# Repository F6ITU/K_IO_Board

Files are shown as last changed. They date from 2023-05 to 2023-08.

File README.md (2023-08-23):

# K_IO_Board
LA2NI's OpenHPSDR I/O Board (Kicad Version)

OpenHPSDR P.A. OpenHPSDR Input/Output board by LA2NI (Munin 400)

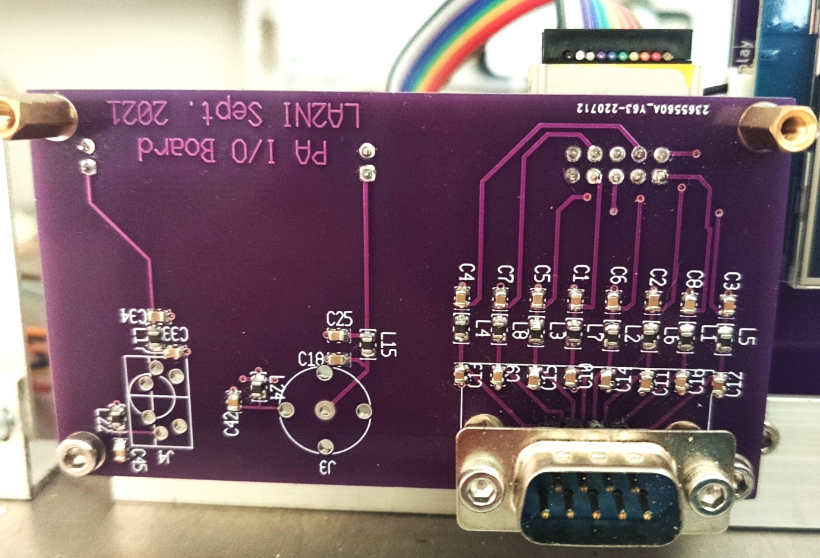
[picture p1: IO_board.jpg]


This picture shows an early design of the I/O board by LA2NI

This I/O board is part of a set consisting of a 400 W LDMos based RF power amplifier (Munin 400), 
a medium power (600 or 1500 W) Zolotarev low pass filter, an Automatic Antenna Tuner (ATU) nickname « Aries » 
and a 4 port antenna switch.

All these developments are the work and intellectual property of Kjell Karlsen LA2NI and Laurence Barker G8NJJ.

This original work can be downloaded from 

https://github.com/LA2NI/

https://github.com/laurencebarker

The I/O board ensures the physical link between the transceiver and the "Munin400/Aries" RF system

For more information, please refer to the Aries documentation (in the G8NJJ github repository)

This board was originally developed in September 2021 by Kjell LA2NI , with UltiBoard EDA. A very early release has been designed
using KiCAD EDA. After some test on a prototype setup, it has been decided to extend this board to offer both P1/output jack and
the full set of J1 signal output and a 12V switched power supply rail for the OpenHPSDR Andromeda interface. All internal or external
"tune" trace that can be found on the original f5 release of the I/O board schematic have been deleted

This design is protected by the CERN Open source/ Open hardware Licence.

Kicad is an Opensource EDA software maintained by the European Reseach Center CERN (Conseil européen pour la recherche nucléaire)

The original work is protected by the TAPR Open Hardware licence
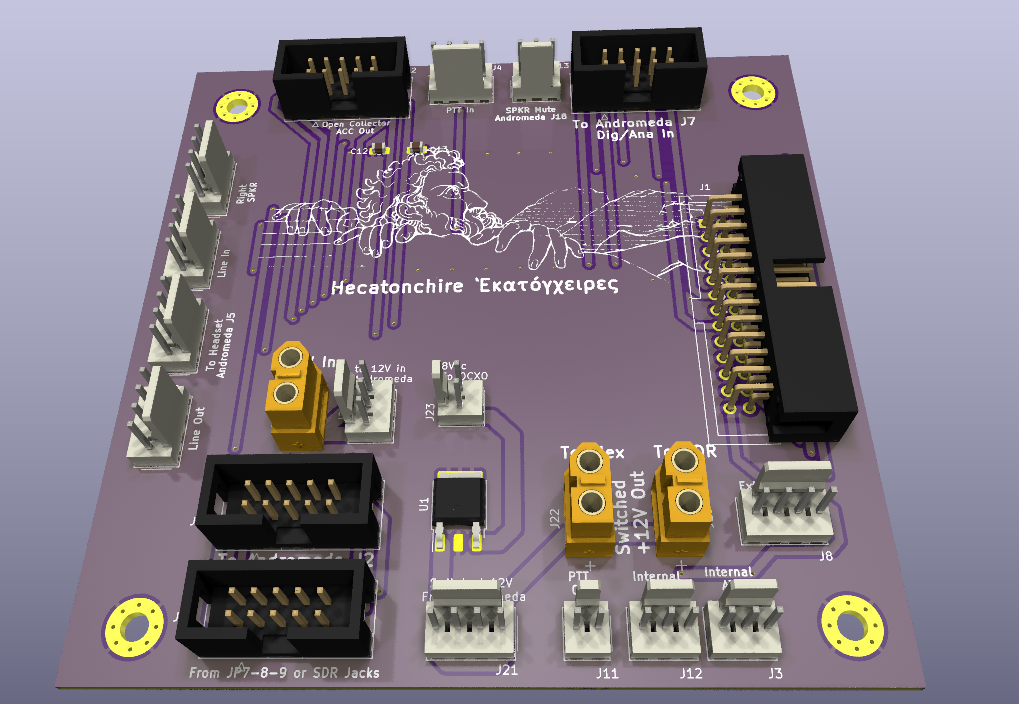
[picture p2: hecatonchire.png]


Gerber files could be downloaded at https://github.com/F6ITU/K_IO_Board/tree/main/Gerber 

An interactive BOM is also available https://github.com/F6ITU/K_IO_Board/tree/main/iBom

This version is -so far- considered as a "final and usable" version. As usual, all improvement suggestions are welcome.

73' , Enjoy

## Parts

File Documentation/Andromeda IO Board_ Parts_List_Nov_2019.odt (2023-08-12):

Andromeda I/O Board Parts List.

Nov. 2019

47 pcs. 10nF Size 0603

C1- C45, C47. Do not install C21, C22, C29, C30, C41

on LINE Out.

1 pcs. 2x13 26 pin Header Molex PN: 70247-2651

J1 Mouser PN: 538-70247-2651

1 pcs. 9 pin Delta Header, Female Harting PN: 09641127235 (https://www.digikey.com/product-detail/en/harting/09641127235/1195-2367-ND/3180950)

J2 DigiKey PN: 1195-2367-ND (https://www.digikey.com/product-detail/en/harting/09641127235/1195-2367-ND/3180950)

Mouser PN: 617-09-64-112-7235

1 pcs. RCA header. Pro-Signal PN: MJ-573P

J11 Farnell PN: 1267399

5 pcs. 3,5mm Stereo Jack Molex PN: 0472570001

J4-J8 Mouser PN: 538-47257-0001

DigiKey PN: WM17366-ND

1 pcs. Header1x3 Molex PN: 38-00-6293

Mouser PN: 538-38-00-6293

1 pcs. Header 1x4 Molex PN: 22-23-2042

Mouser PN: 538-22-23-2042

1 pcs. Header 2x5 10 pin header Molex PN 70246-1003

Mouser PN:538-70246-1003

26pcs. Ferrite Beads Wurth Elektronik PN: 742792514

L1-L20, L22-L27 Mouser PN: 710-742792514

DigiKey PN: 732-1643-2-ND

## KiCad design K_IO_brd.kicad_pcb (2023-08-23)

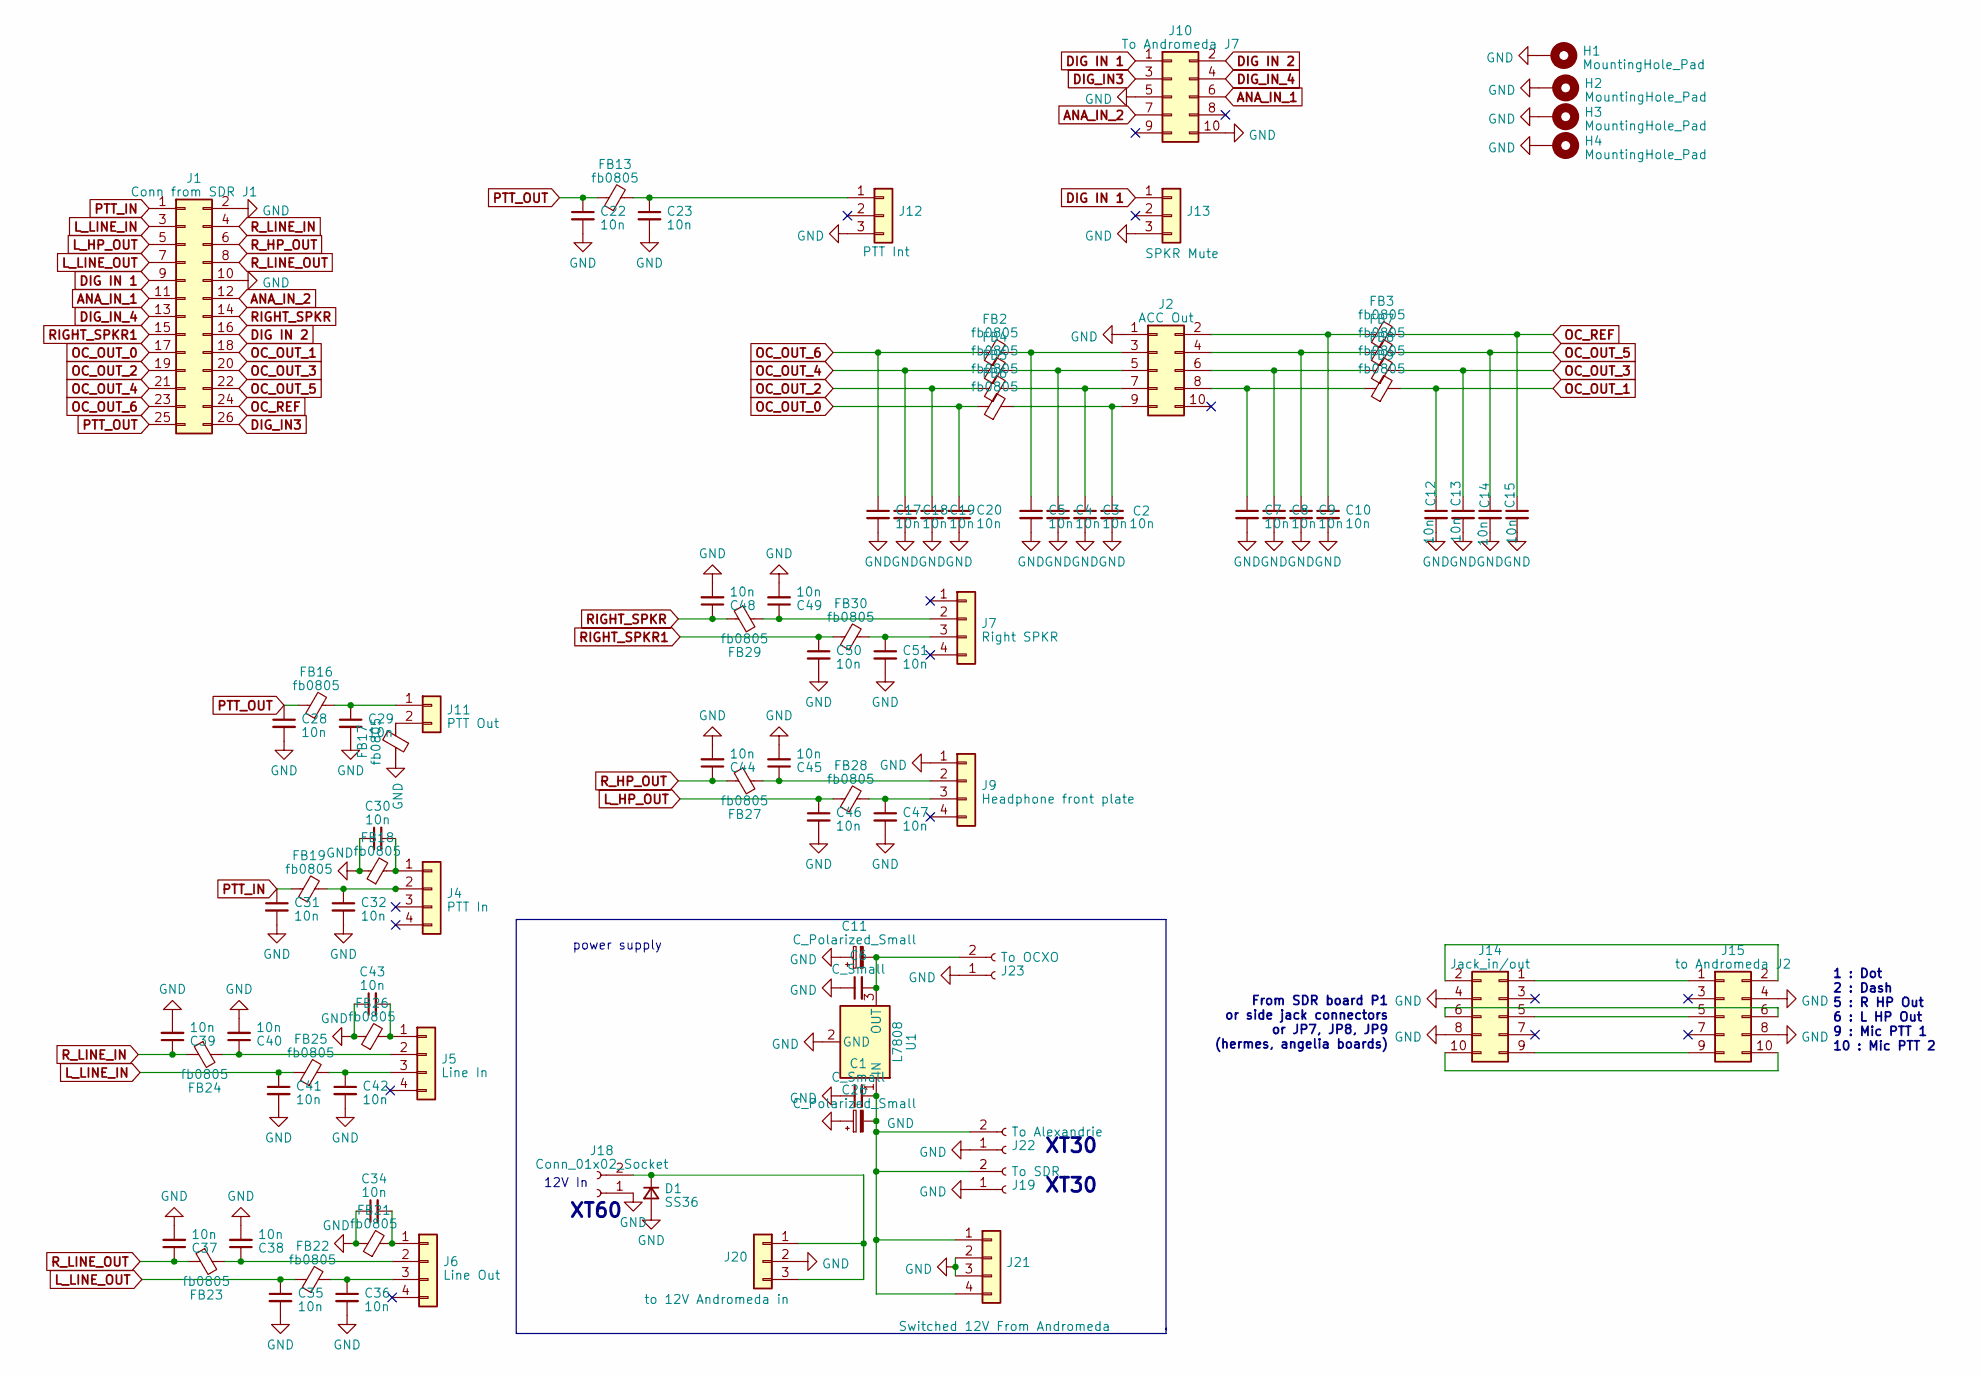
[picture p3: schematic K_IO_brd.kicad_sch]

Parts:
C1, C6: C_Small; C_0805_2012Metric_Pad1.18x1.45mm_HandSolder
C2, C3, C4, C5, C7, C8, C9, C10, C12, C13, C14, C15, C17, C18, C19, C20, C22, C23, C28, C29, C30, C31, C32, C34, C35, C36, C37, C38, C39, C40, C41, C42, C43, C44, C45, C46, C47, C48, C49, C50, C51: 10n; C_0805_2012Metric_Pad1.18x1.45mm_HandSolder
C11, C26: C_Polarized_Small; C_2220_5650Metric_Pad1.97x5.40mm_HandSolder
D1: SS36; D_SMC
FB2, FB3, FB4, FB5, FB6, FB7, FB8, FB9, FB13, FB16, FB17, FB18, FB19, FB21, FB22, FB23, FB24, FB25, FB26, FB27, FB28, FB29, FB30: fb0805; L_0805_2012Metric_Pad1.15x1.40mm_HandSolder
H1, H2, H3, H4: MountingHole_Pad; MountingHole_3.5mm_Pad_Via
J1: Conn from SDR J1; IDC-Header_2x13_P2.54mm_Vertical
J2: ACC Out; IDC-Header_2x05_P2.54mm_Vertical
J4: PTT In; Molex_KK-254_AE-6410-04A_1x04_P2.54mm_Vertical
J5: Line In; Molex_KK-254_AE-6410-04A_1x04_P2.54mm_Vertical
J6: Line Out; Molex_KK-254_AE-6410-04A_1x04_P2.54mm_Vertical
J7: Right SPKR; Molex_KK-254_AE-6410-04A_1x04_P2.54mm_Vertical
J9: Headphone front plate; Molex_KK-254_AE-6410-04A_1x04_P2.54mm_Vertical
J10: To Andromeda J7; IDC-Header_2x05_P2.54mm_Vertical
J11: PTT Out; Molex_KK-254_AE-6410-02A_1x02_P2.54mm_Vertical
J12: PTT Int; Molex_KK-254_AE-6410-03A_1x03_P2.54mm_Vertical
J13: SPKR Mute; Molex_KK-254_AE-6410-03A_1x03_P2.54mm_Vertical
J14: Jack_in/out; IDC-Header_2x05_P2.54mm_Vertical
J15: to Andromeda J2; IDC-Header_2x05_P2.54mm_Vertical
J18: Conn_01x02_Socket; AMASS_XT30U-F_1x02_P5.0mm_Vertical
J19: To SDR; AMASS_XT30U-F_1x02_P5.0mm_Vertical
J20: to 12V Andromeda in; Molex_KK-254_AE-6410-03A_1x03_P2.54mm_Vertical
J21: Switched 12V From Andromeda; Molex_KK-254_AE-6410-04A_1x04_P2.54mm_Vertical
J22: To Alexandrie; AMASS_XT30U-F_1x02_P5.0mm_Vertical
J23: To OCXO; Molex_KK-254_AE-6410-02A_1x02_P2.54mm_Vertical
U1: L7808; TO-252-3_TabPin2

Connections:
ANA_IN_1: J1.11, J10.6
ANA_IN_2: J1.12, J10.7
DIG IN 1: J1.9, J10.1, J13.1
DIG IN 2: J1.16, J10.2
DIG_IN3: J1.26, J10.3
DIG_IN_4: J1.13, J10.4
GND: C1.1, C2.2, C3.2, C4.2, C5.2, C6.1, C7.2, C8.2, C9.2, C10.2, C11.1, C12.2, C13.2, C14.2, C15.2, C17.2, C18.2, C19.2, C20.2, C22.2, C23.2, C26.1, C28.2, C29.2, C30.1, C31.2, C32.2, C34.1, C35.2, C36.2, C37.2, C38.2, C39.2, C40.2, C41.2, C42.2, C43.1, C44.2, C45.2, C46.2, C47.2, C48.2, C49.2, C50.2, C51.2, D1.2 (A), FB17.1, FB18.1, FB21.1, FB26.1, H1.1, H2.1, H3.1, H4.1, J1.2, J1.10, J2.1, J9.1, J10.5, J10.10, J12.3, J13.3, J14.4, J14.8, J15.4, J15.8, J18.1, J19.1, J20.2, J21.2, J21.3, J22.1, J23.1, U1.2 (GND)
L_HP_OUT: C46.1, FB28.1, J1.5
L_LINE_IN: C41.1, FB25.1, J1.3
L_LINE_OUT: C35.1, FB22.1, J1.7
unnamed: D1.1 (K), J18.2, J20.1, J20.3
unnamed: C10.1, FB3.1, J2.2
unnamed: C5.1, FB2.2, J2.3
unnamed: C9.1, FB7.1, J2.4
unnamed: C4.1, FB4.2, J2.5
unnamed: C8.1, FB8.1, J2.6
unnamed: C3.1, FB5.2, J2.7
unnamed: C7.1, FB9.1, J2.8
unnamed: C2.1, FB6.2, J2.9
unnamed: C30.2, FB18.2, J4.1
unnamed: C32.1, FB19.2, J4.2
unnamed: C43.2, FB26.2, J5.1
unnamed: C40.1, FB24.2, J5.2
unnamed: C42.1, FB25.2, J5.3
unnamed: C34.2, FB21.2, J6.1
unnamed: C38.1, FB23.2, J6.2
unnamed: C36.1, FB22.2, J6.3
unnamed: C49.1, FB29.2, J7.2
unnamed: C51.1, FB30.2, J7.3
unnamed: C45.1, FB27.2, J9.2
unnamed: C47.1, FB28.2, J9.3
unnamed: C29.1, FB16.2, J11.1
unnamed: FB17.2, J11.2
unnamed: C23.1, FB13.2, J12.1
unnamed: J14.1, J15.1
unnamed: J14.2, J15.2
unnamed: J14.5, J15.5
unnamed: J14.6, J15.6
unnamed: J14.9, J15.9
unnamed: J14.10, J15.10
unnamed: C1.2, C26.2, J19.2, J21.1, J21.4, J22.2, U1.1 (IN)
unnamed: C6.2, C11.2, J23.2, U1.3 (OUT)
OC_OUT_0: C20.1, FB6.1, J1.17
OC_OUT_1: C12.1, FB9.2, J1.18
OC_OUT_2: C19.1, FB5.1, J1.19
OC_OUT_3: C13.1, FB8.2, J1.20
OC_OUT_4: C18.1, FB4.1, J1.21
OC_OUT_5: C14.1, FB7.2, J1.22
OC_OUT_6: C17.1, FB2.1, J1.23
OC_REF: C15.1, FB3.2, J1.24
PTT_IN: C31.1, FB19.1, J1.1
PTT_OUT: C22.1, C28.1, FB13.1, FB16.1, J1.25
RIGHT_SPKR: C48.1, FB29.1, J1.14
RIGHT_SPKR1: C50.1, FB30.1, J1.15
R_HP_OUT: C44.1, FB27.1, J1.6
R_LINE_IN: C39.1, FB24.1, J1.4
R_LINE_OUT: C37.1, FB23.1, J1.8

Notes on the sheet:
XT60
power supply
XT30
12V In
1 : Dot 2 : Dash 5 : R HP Out 6 : L HP Out 9 : Mic PTT 1 10 : Mic PTT 2
From SDR board P1 or side jack connectors or JP7, JP8, JP9 (hermes, angelia boards)

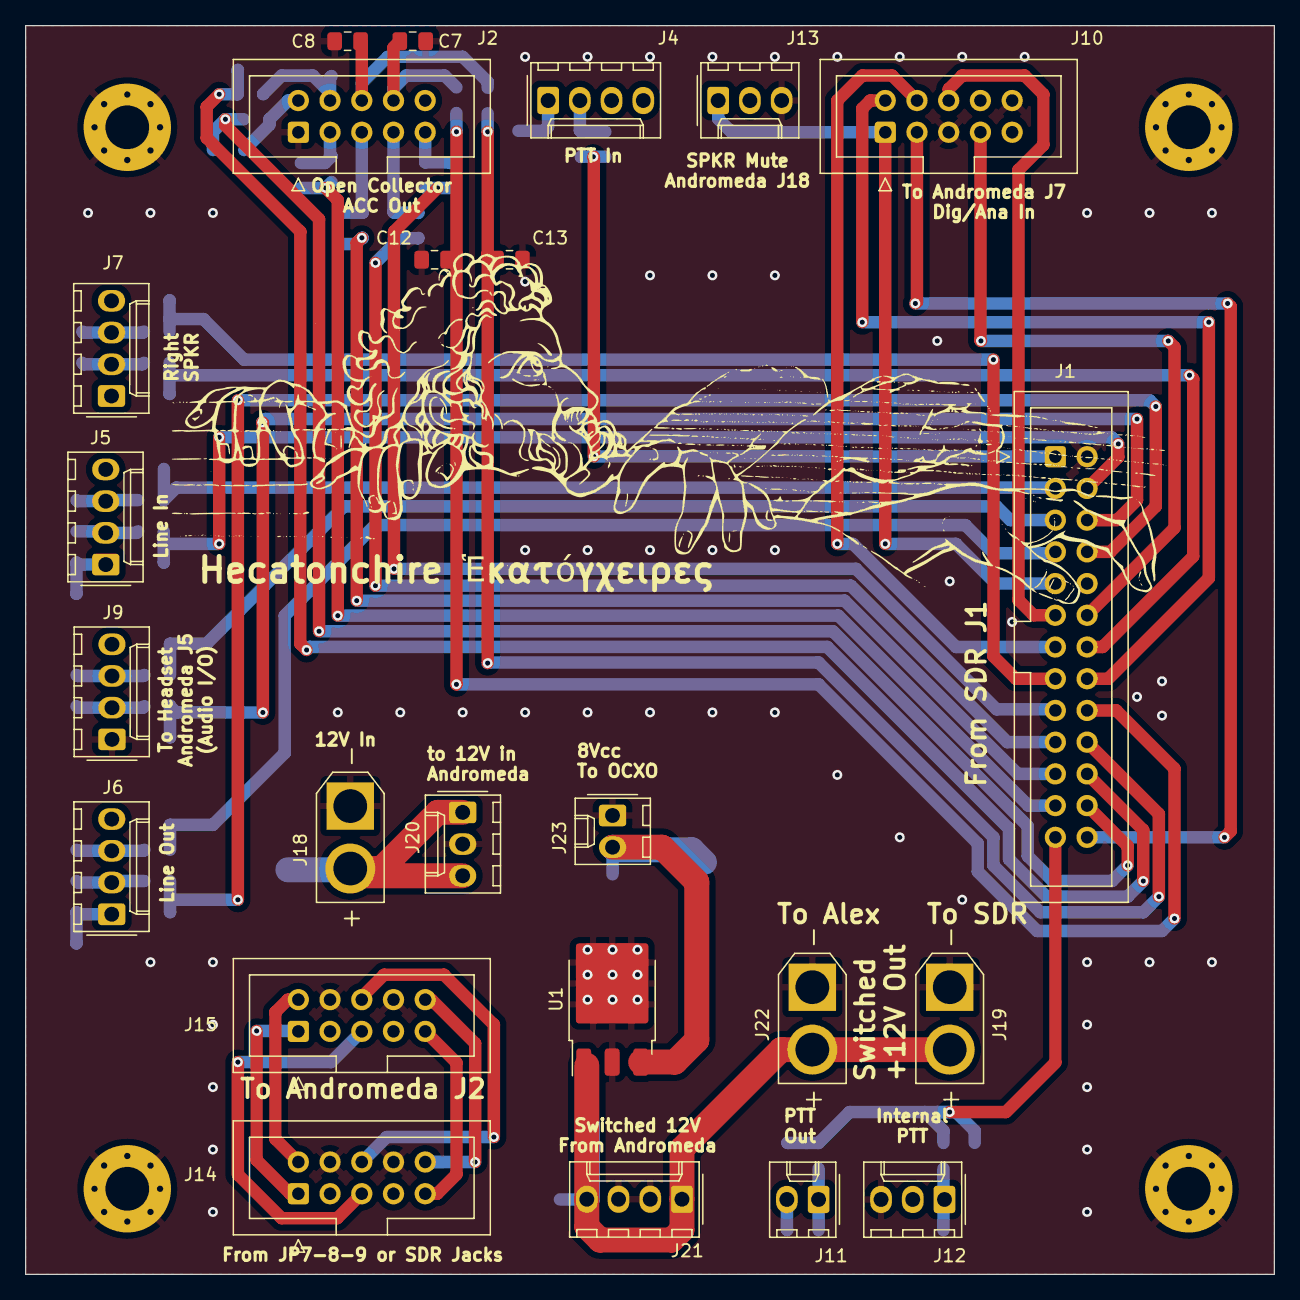
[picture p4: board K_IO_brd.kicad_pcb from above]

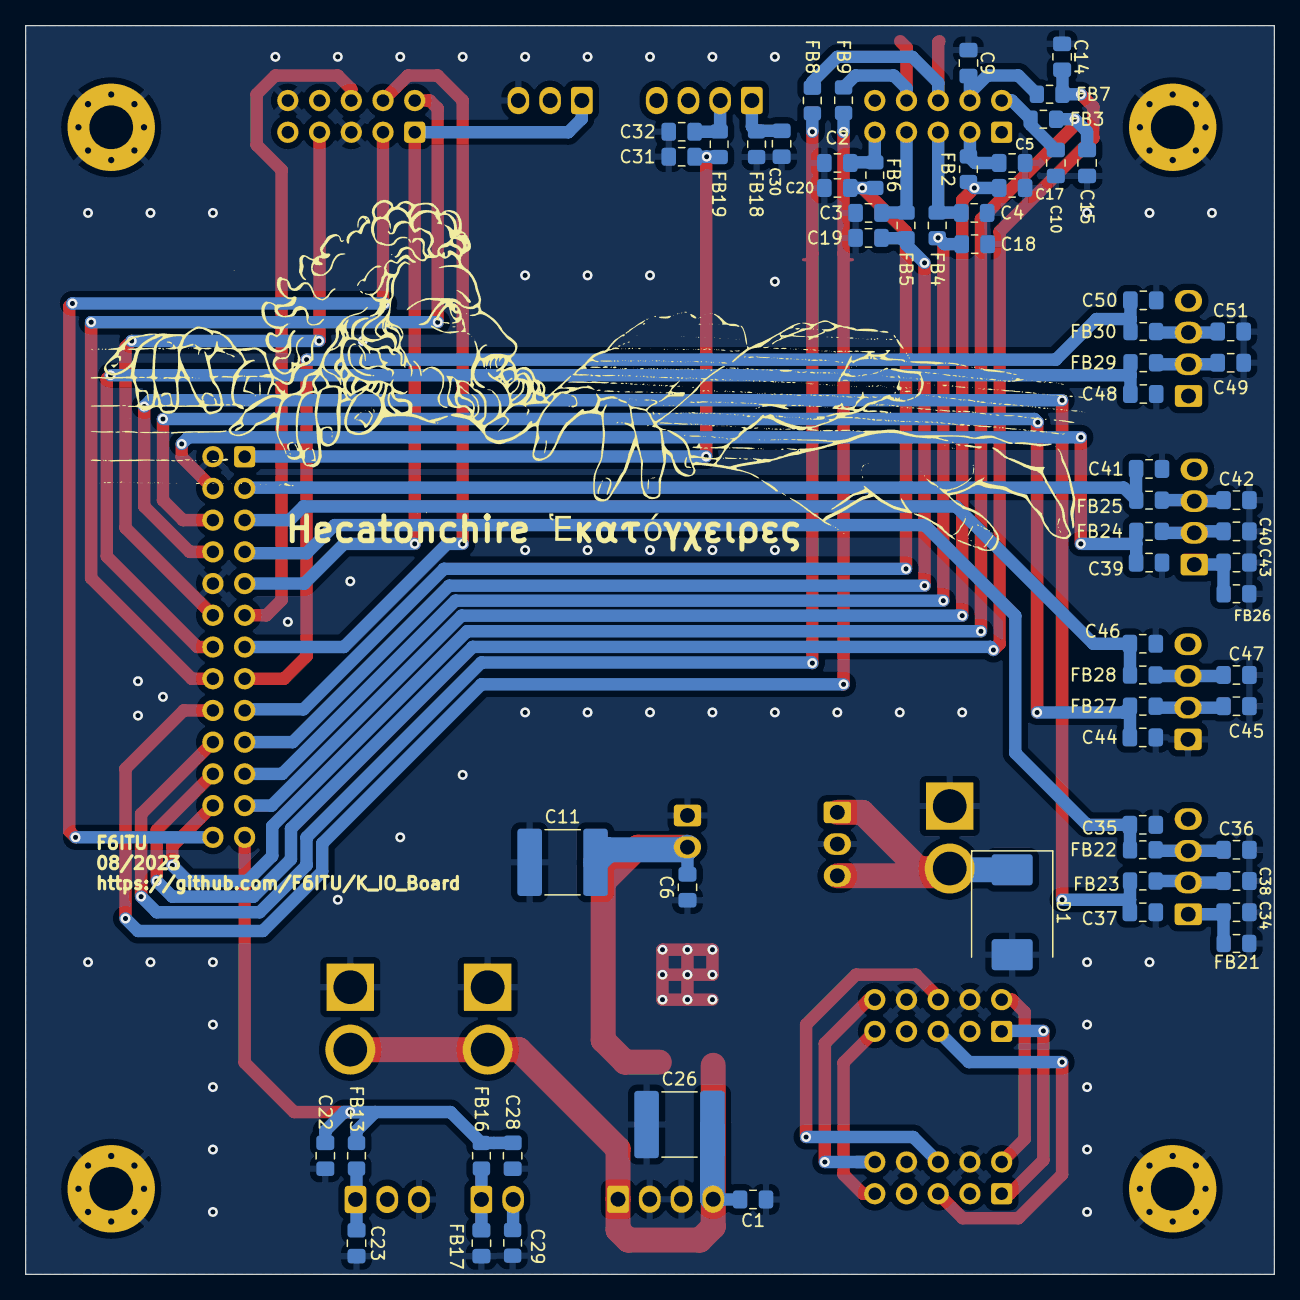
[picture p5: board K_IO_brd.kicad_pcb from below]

Board: 2 copper layers, 100.0 x 100.0 mm, 93 parts (65 on the bottom side), 57 nets.

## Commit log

2023-08-12 major change, full J1 support, 10c10 board
    [K_IO_brd.kicad_pcb, K_IO_brd.kicad_sch]
2023-08-23 minor changes
    [K_IO_brd-B_Cu.gbl, K_IO_brd-B_Mask.gbs, K_IO_brd-B_Paste.gbp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]
